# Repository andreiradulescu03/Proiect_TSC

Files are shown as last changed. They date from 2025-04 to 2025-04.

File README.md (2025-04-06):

# OpenBook – Proiect TSC 2025

Acest proiect reprezinta un prototip de eBook reader open-source, construit in jurul microcontrolerului ESP32-C6 si echipat cu afisaj E-Ink, baterie Li-Po, incarcare prin USB-C, slot microSD si senzori de mediu. Proiectul a inclus realizarea schemei electrice, a placii PCB, a modelului 3D complet si a fisierelor pentru fabricatie.

---

## Diagrama bloc

```mermaid
flowchart TB
  USB-C -->|5V| CHG["Battery Charger MCP73831"]
  CHG -->|Charging| BAT["LiPo Battery"]
  BAT --> LDO["3.3V LDO Regulator"]
  LDO -->|3.3V| ESP["ESP32-C6"]
  LDO -->|3.3V| EPD["E-Ink Display"]
  LDO -->|3.3V| SD["SD Card"]
  LDO -->|3.3V| BME["Sensor BME688"]
  LDO -->|3.3V| RTC["RTC DS3231"]
  LDO -->|3.3V| MAX["Battery Monitor MAX17048"]
  
  ESP -- SPI --> EPD
  ESP -- SPI --> SD
  ESP -- I2C --> BME
  ESP -- I2C --> RTC
  ESP -- I2C --> MAX
  ESP -- GPIO --> BTN["Buttons (3x)"]
```

---

## Functionalitate hardware

- **ESP32-C6** gestioneaza toate perifericele prin GPIO, SPI si I2C
- **Afisajul E-Ink** este controlat prin SPI si are semnale dedicate pentru RESET, DC si BUSY
- **Bateria Li-Po** este incarcata printr-un controler MCP73831 si monitorizata cu MAX17048
- **Senzorul BME688** masoara temperatura, umiditatea, presiunea si compusii volatili
- **Modulul RTC DS3231** mentine ora exacta si permite deep sleep eficient
- **Cardul microSD** este conectat la aceeasi magistrala SPI
- Toate componentele sunt montate pe layer-ul TOP si rutarea este realizata in 2 straturi

---

## Pinout ESP32-C6

| Componenta | Pin ESP32-C6 | Interfata |
|---|---|---|
| E-Ink BUSY | IO3 | GPIO |
| E-Ink DC | IO5 | GPIO |
| E-Ink RESET | IO23 | GPIO |
| E-Ink CS | IO10 | SPI |
| E-Ink MOSI | IO7 | SPI |
| E-Ink SCK | IO6 | SPI |
| SD Card CS | IO4 | SPI |
| SD Card MISO | IO2 | SPI |
| I2C SDA | IO18 | I2C |
| I2C SCL | IO19 | I2C |
| Butoane | GPIO10/11/12 | GPIO |

---

## Fisiere incluse

- `*.sch`, `*.brd` – schema electrica si design-ul PCB
- `Gerber/` – fisiere de productie
- `3D/` – modelul 3D al PCB-ului cu toate componentele atasate (baterie, ecran, carcasa)
- `BOM.csv` – lista de componente
- `README.md` – acest fisier

---

## Observatii

- Traseele de alimentare au latimea de 0.3mm, restul traseelor 0.15mm
- PCB-ul are grosimea de 1mm si contine planuri de masa pe ambele straturi
- Conectorii, ecranul si bateria au fost integrati in modelul 3D si testati pentru incadrare in carcasa
- Carcasa a fost importata si aliniata cu PCB-ul pentru randare
- Fisierele au fost verificate cu ERC si DRC

---

## Disclaimer subtil

Am invatat multe lucruri din acest proiect. Unele despre proiectare electronica. Majoritatea despre autocontrol.

---

# Bill of Materials
| Componenta | Link | Datasheet
| --- | --- |---|
|ESP32_WROVER_BME680_BME680|https://www.snapeda.com/parts/BME680/Bosch/view-part/?welcome=home|https://www.snapeda.com/parts/BME680/Bosch%20Sensortec/datasheet/|
|ESP32_WROVER_EAGLE-LTSPICE_CC0402|https://componentsearchengine.com/Datasheets/2/CC0402MRX5R5BB106.pdf|https://componentsearchengine.com/part-view/CC0402MRX5R5BB106/YAGEO|
|ESP32_WROVER_SPARKFUN-DISCRETESEMI_MOSFET_PCH-DMG2305UX-7|https://componentsearchengine.com/part-view/DMG2305UX-7/Diodes%20Incorporated|https://www.diodes.com//assets/Datasheets/DMG2305UX.pdf|
|ESP32C6_VARISTORCN1812|https://www.mouser.co.uk/ProductDetail/EPCOS-TDK/B72520T0350K062?qs=dEfas%2FXlABIszF52uu7vrg%3D%3D|https://www.tdk-electronics.tdk.com/inf/75/db/CTVS_14/Surge_protection_series.pdf|
|FH34SRJ-24S-0.5SH_99_|https://componentsearchengine.com/part-view/XC6220A331MR-G/Torex|https://product.torexsemi.com/system/files/series/xc6220.pdf|
|MAX17048G+T10|https://www.snapeda.com/parts/MAX17048G+T10/Analog+Devices/view-part/?ref=eda|https://www.snapeda.com/parts/MAX17048G+T10/Analog%20Devices/datasheet/|
|MBR0530|https://ro.mouser.com/ProductDetail/KYOCERA-AVX/SD0805S020S1R0?qs=jCA%252BPfw4LHbpkAoSnwrdjw%3D%3D|https://ro.mouser.com/datasheet/2/40/schottky-3165252.pdf|
|PGB1010603MR|https://www.snapeda.com/parts/PGB1010603MR/Littelfuse/view-part/?ref=eda|https://www.snapeda.com/parts/PGB1010603MR/Littelfuse%20Inc./datasheet/|
|RCL_CPOL-EUCT3528|https://ro.mouser.com/ProductDetail/Vishay-Sprague/TR3B106K025C1300?qs=jCGqFXxTmLdffnuDkXzk1g%3D%3D|https://www.vishay.com/docs/40080/tr3.pdf|
|SAMACSYS_PARTS_USB4110-GF-A|https://componentsearchengine.com/part-view/USB4110-GF-A/GCT%20(GLOBAL%20CONNECTOR%20TECHNOLOGY)|https://gct.co/files/drawings/usb4110.pdf|
|SI1308EDL-T1-GE3|https://componentsearchengine.com/part-view/SI1308EDL-T1-GE3/Vishay|https://componentsearchengine.com/Datasheets/1/SI1308EDL-T1-GE3.pdf|
|SJ|https://grabcad.com/library/solder-jumpers-1||
|USBLC6-2SC6Y|https://www.snapeda.com/parts/USBLC6-2SC6Y/STMicroelectronics/view-part/?ref=eda|https://www.snapeda.com/parts/USBLC6-2SC6Y/STMicroelectronics/datasheet/|
|W25Q512JVEIQ|https://www.snapeda.com/parts/W25Q512JVEIQ/Winbond+Electronics/view-part/?ref=eda|https://www.snapeda.com/parts/W25Q512JVEIQ/Winbond%20Electronics/datasheet/|
|XC6220A331MR-G|https://componentsearchengine.com/part-view/XC6220A331MR-G/Torex|https://product.torexsemi.com/system/files/series/xc6220.pdf|
| ESP32_WROVER_EAGLE-LTSPICE_RR0402  | https://www.snapeda.com/parts/RC0402FR-07226RL/Yageo/view-part/ |https://www.snapeda.com/parts/RC0402FR-07226RL/Yageo/datasheet/
| QWIIC_CONNECTORJS-1MM | https://www.snapeda.com/parts/PRT-14417/SparkFun/view-part/ |https://www.snapeda.com/parts/PRT-14417/SparkFun%20Electronics/datasheet/
|BUTTON_CUSYOMV1|https://industry.panasonic.com/global/en/downloads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|https://industry.panasonic.com/global/en/downloads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
|ESP32_WROVER_EAGLE-LTSPICE_CC0402|https://componentsearchengine.com/part-view/CC0402MRX5R5BB106/YAGEO|https://componentsearchengine.com/Datasheets/2/CC0402MRX5R5BB106.pdf
|CPH3225A|https://www.snapeda.com/parts/CPH3225A/Seiko+Instruments/view-part/?ref=eda|https://www.snapeda.com/parts/CPH3225A/Seiko%20Instruments/datasheet/|
|ADAFRUIT_LEDCHIP-LED0603|https://www.snapeda.com/parts/KP-1608SURCK/Kingbright/view-part/?ref=search&t=LED%200603|https://www.snapeda.com/parts/KP-1608SURCK/Kingbright/datasheet/
|112A-TAAR-R03_ATTEND|https://store.comet.bg/en/Catalogue/Product/43497/|https://store.comet.bg/en/Catalogue/Product/43497/|
|744043680IND_4828-WE-TPC_WRE|https://www.digikey.sg/en/models/1638515|https://www.we-online.com/components/products/datasheet/744043680.pdf
|BD5229G-TR|https://componentsearchengine.com/part-view/BD5229G-TR/ROHM%20Semiconductor|https://datasheet.datasheetarchive.com/originals/distributors/Datasheets_SAMA/f2b9741ef86007909f138d561a359946.pdf|
|CPH3225A|https://www.snapeda.com/parts/CPH3225A/Seiko+Instruments/view-part/?ref=eda|https://www.snapeda.com/parts/CPH3225A/Seiko%20Instruments/datasheet/|
|DS3231SN|https://www.snapeda.com/parts/DS3231SN%23/Analog+Devices/view-part/?ref=eda|https://www.snapeda.com/parts/DS3231SN%23/Analog%20Devices/datasheet/|
|ESP32-C6-WROOM-1-N8|https://www.snapeda.com/parts/ESP32-C6-WROOM-1-N8/Espressif+Systems/view-part/?ref=eda|https://www.snapeda.com/parts/ESP32-C6-WROOM-1-N8/Espressif%20Systems/datasheet/
|MCP73831|https://www.digikey.com/en/models/1874108|https://ww1.microchip.com/downloads/aemDocuments/documents/APID/ProductDocuments/DataSheets/MCP73831-Family-Data-Sheet-DS20001984H.pdf|

---

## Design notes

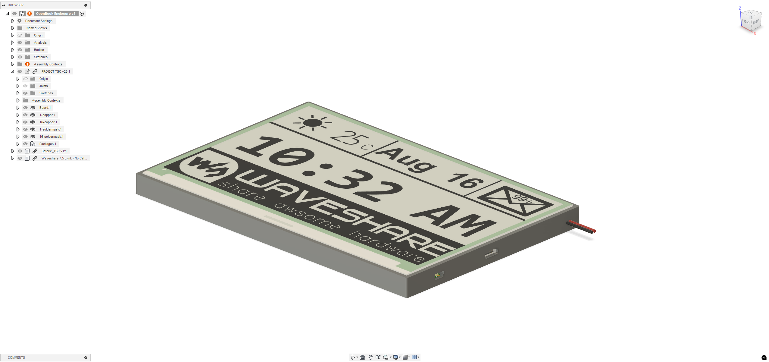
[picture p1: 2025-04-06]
Images/schema_pcb_3d_complet.png

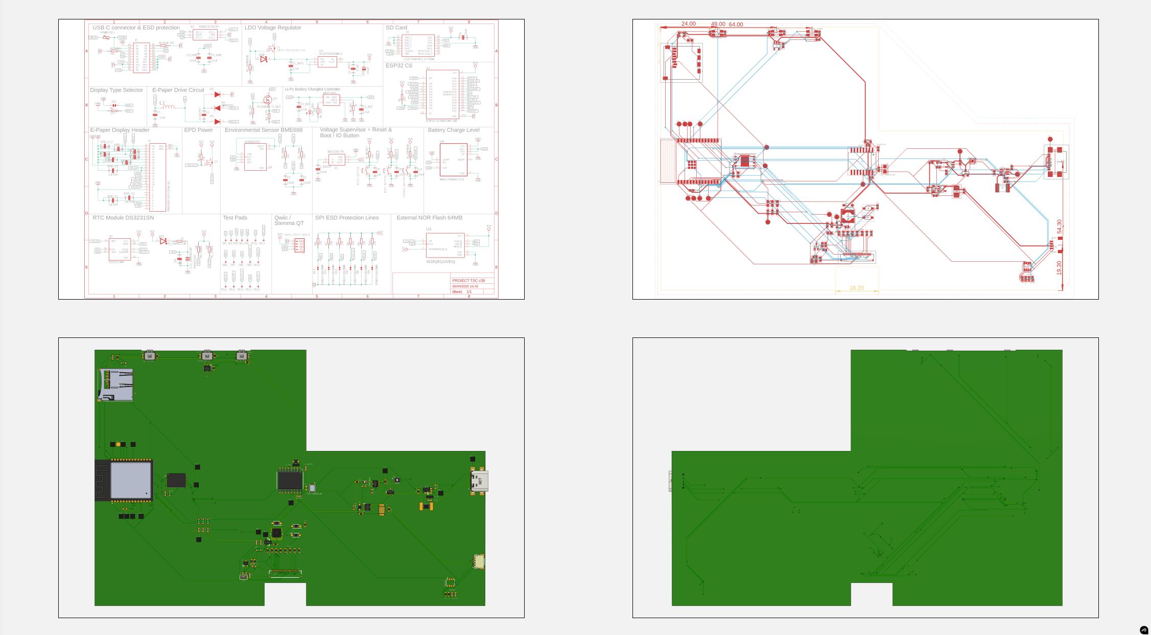
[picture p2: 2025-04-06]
Images/main.png

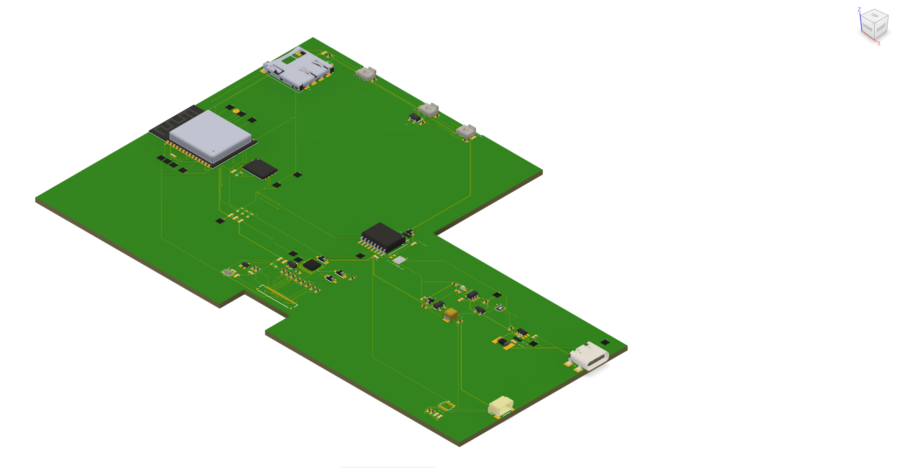
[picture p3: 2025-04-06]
Images/schema_pcb_3d_placa.png

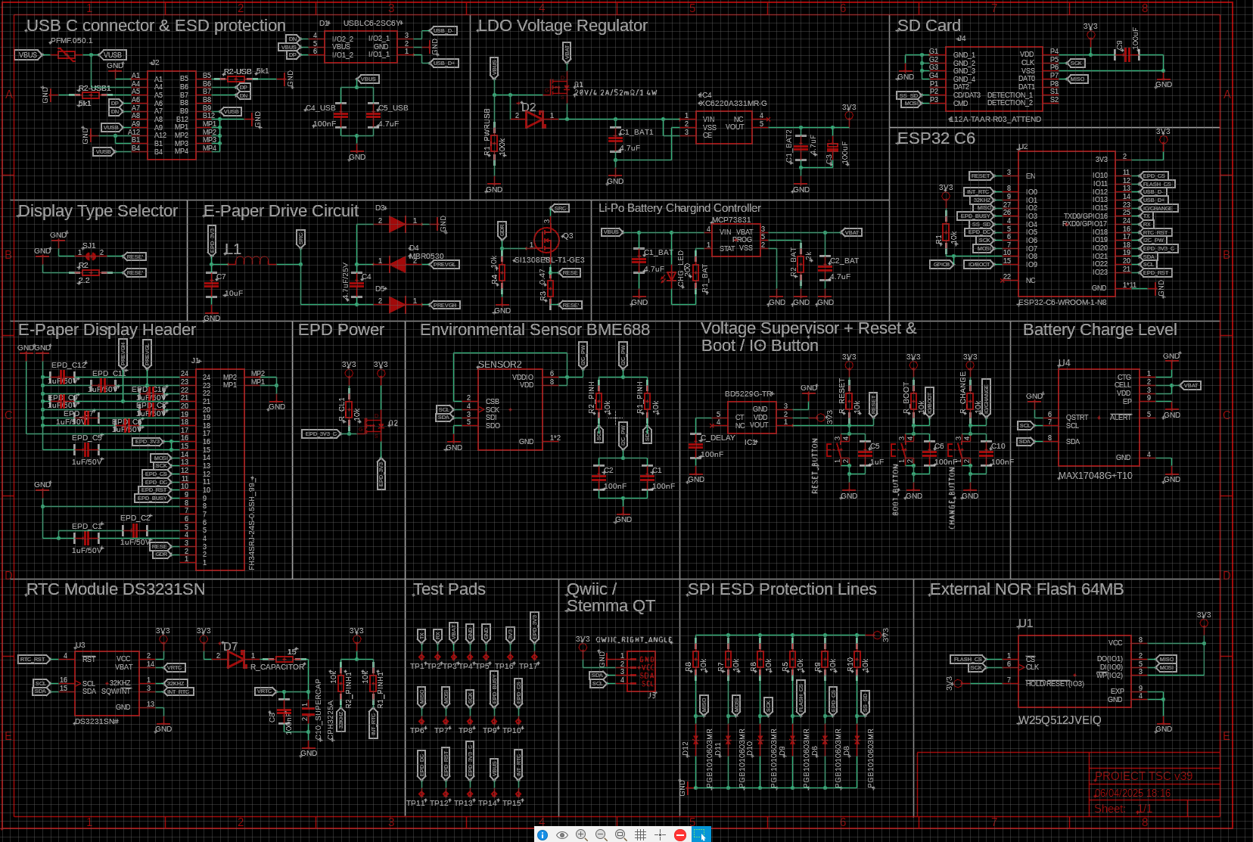
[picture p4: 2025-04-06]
Images/schema_electrica.png

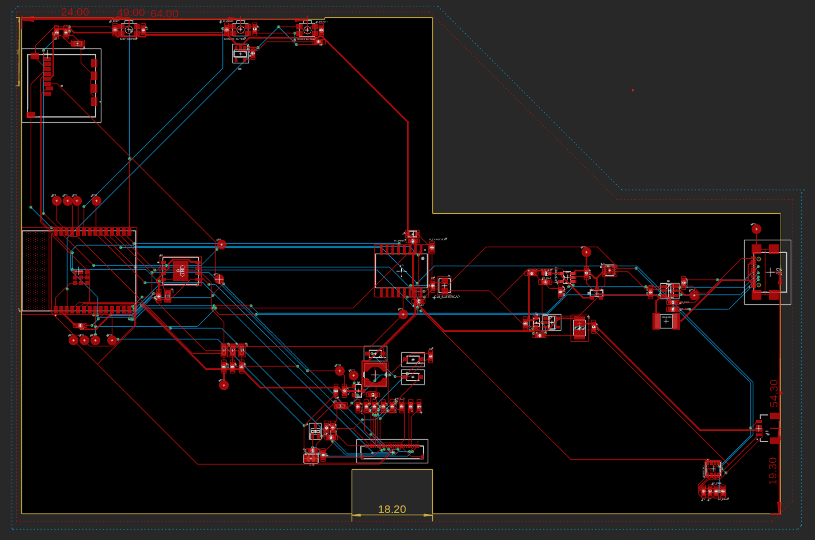
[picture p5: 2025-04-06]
Images/schema_pcb.png

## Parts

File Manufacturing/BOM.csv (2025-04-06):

Qty | Value | Device | Package | Parts | Description | ARROW_PART_NUMBER | ARROW_PRICE-STOCK | AVAILABILITY | CENTROID_NOT_SPECIFIED | CHECK_PRICES | COPYRIGHT | DATASHEET | DESCRIPTION | DIGIKEY_DESCRIPTION | DIGIKEY_PART_NUMBER | HEIGHT | LEAD_FREE | MANUFACTURER_NAME | MANUFACTURER_PART_NUMBER | MF | MFR_NAME | MOUSER_PART_NUMBER | MOUSER_PRICE-STOCK | MOUSER_TESTING_PART_NUMBER | MOUSER_TESTING_PRICE-STOCK | MP | MPN | PACKAGE | POPULARITY | PREFIX | PRICE | PROD_ID | PURCHASE-URL | ROHS | SNAPEDA_LINK | SPICEMODEL | SPICEPREFIX | TEMPERATURE_RANGE_HIGH | TEMPERATURE_RANGE_LOW | TP_SIGNAL_NAME | VALUE
1 |  | ADAFRUIT_LEDCHIP-LED0603 | ADAFRUIT_CHIP-LED0603 | CHG_LED | LED
1 |  | SJ | SJ | SJ1 | SMD solder JUMPER |  |  |  |  |  |  |  |  |  |  |  |  |  |  |  |  |  |  |  |  |  |  |  | 3
1 | 0.47 | ESP32_WROVER_EAGLE-LTSPICE_RR0402 | ESP32_WROVER_EAGLE-LTSPICE_R0402 | R3 | RESISTOR, European symbol |  |  |  |  |  |  |  |  |  |  |  |  |  |  |  |  |  |  |  |  |  |  |  |  |  |  |  |  |  |  | NONE | R
1 | 100k | ESP32_WROVER_EAGLE-LTSPICE_RR0402 | ESP32_WROVER_EAGLE-LTSPICE_R0402 | R1_PWRUSB | RESISTOR, European symbol |  |  |  |  |  |  |  |  |  |  |  |  |  |  |  |  |  |  |  |  |  |  |  |  |  |  |  |  |  |  | NONE | R
7 | 100nF | EAGLE-LTSPICE_CC0402 | EAGLE-LTSPICE_C0402 | C1, C2, C4_USB, C6, C8, C10, C_DELAY | CAPACITOR, European symbol |  |  |  |  |  |  |  |  |  |  |  |  |  |  |  |  |  |  |  |  |  |  |  |  |  |  |  |  |  |  | NONE | C
1 | 100uF | EAGLE-LTSPICE_CC0402 | EAGLE-LTSPICE_C0402 | C9 | CAPACITOR, European symbol |  |  |  |  |  |  |  |  |  |  |  |  |  |  |  |  |  |  |  |  |  |  |  |  |  |  |  |  |  |  | NONE | C
1 | 100uF | RCL_CPOL-EUCT3528 | RCL_CT3528 | C3 | POLARIZED CAPACITOR, European symbol |  |  |  |  |  |  |  |  |  |  |  |  |  |  |  |  |  |  |  |  |  |  |  | 0 |  |  |  |  |  |  |  | C
16 | 10k | ESP32_WROVER_EAGLE-LTSPICE_RR0402 | ESP32_WROVER_EAGLE-LTSPICE_R0402 | R1, R1_PINH, R1_PINH1, R2_PINH, R2_PINH1, R4, R5, R6, R7, R8, R9, R10, R_BOOT, R_CHANGE, R_CL1, R_RESET | RESISTOR, European symbol |  |  |  |  |  |  |  |  |  |  |  |  |  |  |  |  |  |  |  |  |  |  |  |  |  |  |  |  |  |  | NONE | R
1 | 10uF | EAGLE-LTSPICE_CC0402 | EAGLE-LTSPICE_C0402 | C7 | CAPACITOR, European symbol |  |  |  |  |  |  |  |  |  |  |  |  |  |  |  |  |  |  |  |  |  |  |  |  |  |  |  |  |  |  | NONE | C
1 | 112A-TAAR-R03_ATTEND | 112A-TAAR-R03_ATTEND | 112ATAARR03ATTEND | J4 | Micro SD Card Socket, Push-Push Type, Top Mount, SMT, H=1.83mm, 10u |  |  |  |  |  |  |  | Micro SD Card Socket | Push-Push Type | Top Mount | SMT | H=1.83mm | 10u |  |  | 1.9mm |  | ATTEND | 112A-TAAR-R03 ATTEND
1 | 15 | ESP32_WROVER_EAGLE-LTSPICE_RR0402 | ESP32_WROVER_EAGLE-LTSPICE_R0402 | R_CAPACITOR | RESISTOR, European symbol |  |  |  |  |  |  |  |  |  |  |  |  |  |  |  |  |  |  |  |  |  |  |  |  |  |  |  |  |  |  | NONE | R
1 | 1uF | EAGLE-LTSPICE_CC0402 | EAGLE-LTSPICE_C0402 | C5 | CAPACITOR, European symbol |  |  |  |  |  |  |  |  |  |  |  |  |  |  |  |  |  |  |  |  |  |  |  |  |  |  |  |  |  |  | NONE | C
10 | 1uF/50V | EAGLE-LTSPICE_CC0402 | EAGLE-LTSPICE_C0402 | EPD_C1, EPD_C2, EPD_C5, EPD_C6, EPD_C7, EPD_C8, EPD_C9, EPD_C10, EPD_C11, EPD_C12 | CAPACITOR, European symbol |  |  |  |  |  |  |  |  |  |  |  |  |  |  |  |  |  |  |  |  |  |  |  |  |  |  |  |  |  |  | NONE | C
1 | 2.2 | ESP32_WROVER_EAGLE-LTSPICE_RR0402 | ESP32_WROVER_EAGLE-LTSPICE_R0402 | R2 | RESISTOR, European symbol |  |  |  |  |  |  |  |  |  |  |  |  |  |  |  |  |  |  |  |  |  |  |  |  |  |  |  |  |  |  | NONE | R
1 | 200 | ESP32_WROVER_EAGLE-LTSPICE_RR0402 | ESP32_WROVER_EAGLE-LTSPICE_R0402 | R1_BAT | RESISTOR, European symbol |  |  |  |  |  |  |  |  |  |  |  |  |  |  |  |  |  |  |  |  |  |  |  |  |  |  |  |  |  |  | NONE | R
2 | 20V/4.2A/52mO/1.4W | ESP32_WROVER_SPARKFUN-DISCRETESEMI_MOSFET_PCH-DMG2305UX-7 | ESP32_WROVER_SPARKFUN-DISCRETESEMI_SOT23-3 | Q1, Q2 | P-channel MOSFETs |  |  |  |  |  |  |  |  |  |  |  |  |  |  |  |  |  |  |  |  |  |  |  |  |  |  | TRAN-14388 |  |  |  |  |  |  |  |  | 20V/4.2A/52mO/1.4W
1 | 2k | ESP32_WROVER_EAGLE-LTSPICE_RR0402 | ESP32_WROVER_EAGLE-LTSPICE_R0402 | R2_BAT | RESISTOR, European symbol |  |  |  |  |  |  |  |  |  |  |  |  |  |  |  |  |  |  |  |  |  |  |  |  |  |  |  |  |  |  | NONE | R
5 | 4.7uF | EAGLE-LTSPICE_CC0402 | EAGLE-LTSPICE_C0402 | C1_BAT, C1_BAT1, C1_BAT2, C2_BAT, C5_USB | CAPACITOR, European symbol |  |  |  |  |  |  |  |  |  |  |  |  |  |  |  |  |  |  |  |  |  |  |  |  |  |  |  |  |  |  | NONE | C
1 | 4.7uF/25V | EAGLE-LTSPICE_CC0402 | EAGLE-LTSPICE_C0402 | C4 | CAPACITOR, European symbol |  |  |  |  |  |  |  |  |  |  |  |  |  |  |  |  |  |  |  |  |  |  |  |  |  |  |  |  |  |  | NONE | C
2 | 5k1 | ESP32_WROVER_EAGLE-LTSPICE_RR0402 | ESP32_WROVER_EAGLE-LTSPICE_R0402 | R2-USB, R2-USB1 | RESISTOR, European symbol |  |  |  |  |  |  |  |  |  |  |  |  |  |  |  |  |  |  |  |  |  |  |  |  |  |  |  |  |  |  | NONE | R
1 | 68uH | 744043680IND_4828-WE-TPC_WRE | IND_4828-WE-TPC_WRE | L1 |  |  |  |  |  |  | Copyright (C) 2024 Ultra Librarian. All rights reserved. |  |  |  |  |  |  |  | 744043680 |  | Wurth Electronics
1 | BD5229G-TR | BD5229G-TR | SOT95P280X125-5N | IC1 | Voltage Detector with Adjustable Delay Time: CMOS processes are utilized to develop high precision, low current consumption CMOS reset ICs that allow arbitrary setting of the delay time. The extensive lineup includes both Nch Open Drain and CMOS output types in a wide range of detection voltages (from 2.3V to 6.0V, in 0.1V steps), enabling selection of the ideal solution based on customer requirements. In addition, the entire series is of course both lead-free and RoHS-compliant. |  |  |  |  |  |  |  | Voltage Detector with Adjustable Delay Time: CMOS processes are utilized to develop high precision | low current consumption CMOS reset ICs that allow arbitrary setting of the delay time. The extensive lineup includes both Nch Open Drain and CMOS output types in a wide range of detection voltages (from 2.3V to 6.0V | in 0.1V steps) | enabling selection of the ideal solution based on customer requirements. In addition | the entire series is of course both lead-free and RoHS-compliant. |  |  | 1.25mm |  | ROHM Semiconductor | BD5229G-TR |  |  | 755-BD5229G-TR | https://www.mouser.co.uk/ProductDetail/ROHM-Semiconductor/BD5229G-TR?qs=4kLU8WoGk0vvnhrrYwdszw%3D%3D
3 | BUTTON_CUSYOMV1 | BUTTON_CUSYOMV1 | MYBUTTON | BOOT_BUTTON, CHANGE_BUTTON, RESET_BUTTON
1 | CPH3225A | CPH3225A | CAPCP3225X100N | C10_SUPERCAP | Cap 0.011F 3.3V 1210 Flat Check availability |  |  | Not in stock |  | https://www.snapeda.com/parts/CPH3225A/Seiko+Instruments/view-part/?ref=eda |  |  | 11 mF (EDLC) Supercapacitor 3.3 V 1210 (3225 Metric) - - |  |  |  |  |  |  | Seiko Instruments |  |  |  |  |  | CPH3225A |  | 1210 Seiko |  |  | None |  | https://www.snapeda.com/api/url_track_click_mouser/?unipart_id=562593&manufacturer=Seiko Instruments&part_name=CPH3225A&search_term=None |  | https://www.snapeda.com/parts/CPH3225A/Seiko+Instruments/view-part/?ref=snap
1 | DS3231SN# | DS3231SN# | SOIC127P1032X265-16N | U3 | Real Time Clock Serial 16-Pin SOIC W T/R Check availability |  |  | In Stock |  | https://www.snapeda.com/parts/DS3231SN%23/Analog+Devices/view-part/?ref=eda |  |  | Extremely Accurate I²C-Integrated RTC/TCXO/Crystal |  |  |  |  |  |  | Analog Devices |  |  |  |  |  | DS3231SN# |  | SOIC-16 Maxim |  |  | None |  | https://www.snapeda.com/api/url_track_click_mouser/?unipart_id=99048&manufacturer=Analog Devices&part_name=DS3231SN#&search_term=None |  | https://www.snapeda.com/parts/DS3231SN%23/Analog+Devices/view-part/?ref=snap
1 | ESP32-C6-WROOM-1-N8 | ESP32-C6-WROOM-1-N8 | XCVR_ESP32-C6-WROOM-1-N8 | U2 | Check availability |  |  | In Stock |  | https://www.snapeda.com/parts/ESP32-C6-WROOM-1-N8/Espressif+Systems/view-part/?ref=eda |  |  | Multiprotocol Modules ESP32-C6 module | Wi-Fi 6 in 2.4 GHz band | Bluetooth 5 | Zigbee 3.0 and Thread. ESP34-WROOM Compatible - ENGINEERING SAMPLE |  |  |  |  |  |  | Espressif Systems |  |  |  |  |  | ESP32-C6-WROOM-1-N8 |  | None |  |  | None |  |  |  | https://www.snapeda.com/parts/ESP32-C6-WROOM-1-N8/Espressif+Systems/view-part/?ref=snap
1 | ESP32C6_VARISTORCN1812 | ESP32C6_VARISTORCN1812 | ESP32C6_VARISTOR_CT/CN1812 | PFMF.050.1 | VARISTOR |  |  |  |  |  |  |  |  |  |  |  |  |  |  |  |  |  |  |  |  |  |  |  | 0
2 | ESP32_WROVER_AVX---SD0805S020S1R0_AVX_SD0805S020S1R0_0_0AVX_SD0805S020S1R0_0_0 | ESP32_WROVER_AVX---SD0805S020S1R0_AVX_SD0805S020S1R0_0_0AVX_SD0805S020S1R0_0_0 | ESP32_WROVER_AVX---SD0805S020S1R0_AVX_SD0805S020S1R0_0 | D2, D7 | Schottky Barrier Rectifier Diode |  |  |  | No |  |  | http://datasheets.avx.com/schottky.pdf |  | DIODE SCHOTTKY 20V 1A 0805 | 478-7800-1-ND |  | yes |  |  | AVX |  | 581-SD0805S020S1R0 |  |  |  |  |  | 0805 (2012 metric) |  | D |  |  |  | yes |  |  |  | +125°C | -55°C
1 | ESP32_WROVER_BME680_BME680 | ESP32_WROVER_BME680_BME680 | ESP32_WROVER_BME680_PSON80P300X300X100-8N | SENSOR2 | Integrated Environmental Unit |  |  | Unavailable |  |  |  |  | Integrated Environmental Unit |  |  |  |  |  |  | Bosch Sensortec |  |  |  |  |  | BME680 |  | LGA-8 Bosch Tools |  |  | None
1 | ESP32_WROVER_SPARKFUN-IC-POWER_MCP73831 | ESP32_WROVER_SPARKFUN-IC-POWER_MCP73831 | ESP32_WROVER_SPARKFUN-IC-POWER_SOT23-5 | MCP73831 | MCP73831T Li-Ion, Li-Pol Controller |  |  |  |  |  |  |  |  |  |  |  |  |  |  |  |  |  |  |  |  |  |  |  |  |  |  | IC-09995
1 | FH34SRJ-24S-0.5SH_99_ | FH34SRJ-24S-0.5SH_99_ | FH34SRJ24S05SH99 | J1 | (0.50mm) Surface Mount, Right Angle |  |  |  |  |  |  |  | 24 Position FFC | FPC Connector Contacts | (0.50mm) Surface Mount | Right Angle |  |  | 1.1mm |  | Hirose | FH34SRJ-24S-0.5SH(99) |  |  | 798-FH34SRJ24S05SH99 | https://www.mouser.co.uk/ProductDetail/Hirose-Connector/FH34SRJ-24S-0.5SH99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
1 | MAX17048G+T10 | MAX17048G+T10 | SON50P200X200X80-9N | U4 | Check availability |  |  | In Stock |  | https://www.snapeda.com/parts/MAX17048G+T10/Analog+Devices/view-part/?ref=eda |  |  | 3µA 1-Cell/2-Cell Fuel Gauge with ModelGauge |  |  |  |  |  |  | Analog Devices |  |  |  |  |  | MAX17048G+T10 |  | TDFN-8 Maxim |  |  | None |  | https://www.snapeda.com/api/url_track_click_mouser/?unipart_id=329239&manufacturer=Analog Devices&part_name=MAX17048G+T10&search_term=None |  | https://www.snapeda.com/parts/MAX17048G+T10/Analog+Devices/view-part/?ref=snap
3 | MBR0530 | MBR0530 | SOD3716X135N | D3, D4, D5 | ON SEMICONDUCTOR - MBR0530 - DIODE, SCHOTTKY, 0.5A, 30V, SOD-123 |  |  | In Stock |  | https://www.snapeda.com/parts/MBR0530/Onsemi/view-part/?ref=eda |  |  | Diode Schottky 30 V 500mA Surface Mount SOD-123 |  |  |  |  |  |  | ON Semiconductor |  |  |  |  |  | MBR0530 |  | SOD-123-2 ON Semiconductor |  |  | None |  | https://www.snapeda.com/api/url_track_click_mouser/?unipart_id=179458&manufacturer=ON Semiconductor&part_name=MBR0530&search_term=None |  | https://www.snapeda.com/parts/MBR0530/Onsemi/view-part/?ref=snap
6 | PGB1010603MR | PGB1010603MR | DIOC1608X36N | D6, D8, D9, D10, D11, D12 | Check availability |  |  | In Stock |  | https://www.snapeda.com/parts/PGB1010603MR/Littelfuse/view-part/?ref=eda |  |  | 150V (Typ) Clamp - Ipp Tvs Diode Surface Mount 0603 (1608 Metric) |  |  |  |  |  |  | Littelfuse Inc. |  |  |  |  |  | PGB1010603MR |  | 0603 Littelfuse Inc. |  |  | None |  | https://www.snapeda.com/api/url_track_click_mouser/?unipart_id=5659453&manufacturer=Littelfuse Inc.&part_name=PGB1010603MR&search_term=None |  | https://www.snapeda.com/parts/PGB1010603MR/Littelfuse/view-part/?ref=snap
1 | QWIIC_RIGHT_ANGLE | QWIIC_CONNECTORJS-1MM | JST04_1MM_RA | J3 | SparkFun I2C Standard Qwiic Connector |  |  |  |  |  |  |  |  |  |  |  |  |  |  |  |  |  |  |  |  |  |  |  |  |  |  | CONN-13694 |  |  |  |  |  |  |  |  | QWIIC_RIGHT_ANGLE
1 | SAMACSYS_PARTS_USB4110-GF-A | SAMACSYS_PARTS_USB4110-GF-A | SAMACSYS_PARTS_USB4110GFA | J2 | CONN USB 2.0 TYPE-C R/A SMT |  |  |  |  |  |  |  | CONN USB 2.0 TYPE-C R/A SMT |  |  | 3.26mm |  | GCT (GLOBAL CONNECTOR TECHNOLOGY) | USB4110-GF-A |  |  | 640-USB4110-GF-A | https://www.mouser.co.uk/ProductDetail/GCT/USB4110-GF-A?qs=KUoIvG%2F9IlYiZvIXQjyJeA%3D%3D
1 | SI1308EDL-T1-GE3 | SI1308EDL-T1-GE3 | SOT65P210X110-3N | Q3 | MOSFET N-Ch 30V 1.5A TrenchFET SC70 Vishay Si1308EDL-T1-GE3 N-channel MOSFET Transistor, 1.5 A, 30 V, 3-Pin SC-70 |  |  | In Stock |  | https://www.snapeda.com/parts/SI1308EDL-T1-GE3/Vishay+Siliconix/view-part/?ref=eda |  |  | Si1308EDL-T1-GE3 N-channel MOSFET Transistor | 1.5 A | 30 V | 3-Pin SC-70 | Siliconix / Vishay SI1308EDL-T1-GE3 |  |  |  |  |  |  | Vishay Siliconix |  |  |  |  |  | SI1308EDL-T1-GE3 |  | SOT-323 Vishay Semiconductor |  |  | None |  | https://www.snapeda.com/api/url_track_click_mouser/?unipart_id=274603&manufacturer=Vishay Siliconix&part_name=SI1308EDL-T1-GE3&search_term=None |  | https://www.snapeda.com/parts/SI1308EDL-T1-GE3/Vishay+Siliconix/view-part/?ref=snap
17 | TPTP20R | TPTP20R | TP20R | TP1, TP2, TP3, TP4, TP5, TP6, TP7, TP8, TP9, TP10, TP11, TP12, TP13, TP14, TP15, TP16, TP17 | Test pad |  |  |  |  |  |  |  |  |  |  |  |  |  |  |  |  |  |  |  |  |  |  |  | 2
1 | USBLC6-2SC6Y | USBLC6-2SC6Y | SOT95P280X145-6N | D1 | Low Cap. ESD Protection Auto SOT-23-6 STMicroelectronics USBLC6-2SC6Y, Dual Uni-Directional TVS Diode Array, 6-Pin SOT-23 |  |  | In Stock |  | https://www.snapeda.com/parts/USBLC6-2SC6Y/STMicroelectronics/view-part/?ref=eda |  |  | 17V Clamp 5A (8/20µs) Ipp Tvs Diode Surface Mount SOT-23-6 |  |  |  |  |  |  | STMicroelectronics |  |  |  |  |  | USBLC6-2SC6Y |  | SOT-23-6 STMicroelectronics |  |  | None |  |  |  | https://www.snapeda.com/parts/USBLC6-2SC6Y/STMicroelectronics/view-part/?ref=snap
1 | W25Q512JVEIQ | W25Q512JVEIQ | SON127P600X800X80-9N | U1 | Check availability |  |  | In Stock |  | https://www.snapeda.com/parts/W25Q512JVEIQ/Winbond+Electronics/view-part/?ref=eda |  |  | FLASH - NOR Memory IC 512Mb (64M x 8) SPI - Quad I/O 133 MHz 8-WSON (8x6) |  |  |  |  |  |  | Winbond Electronics |  |  |  |  |  | W25Q512JVEIQ |  | Package |  |  | None |  |  |  | https://www.snapeda.com/parts/W25Q512JVEIQ/Winbond+Electronics/view-part/?ref=snap
1 | XC6220A331MR-G | XC6220A331MR-G | SOT95P280X120-5N | IC4 | LDO Voltage Regulators |  |  |  |  |  |  |  | LDO Voltage Regulators |  |  | 1.2mm |  | Torex | XC6220A331MR-G |  |  | 865-XC6220A331MR-G | https://www.mouser.co.uk/ProductDetail/Torex-Semiconductor/XC6220A331MR-G?qs=AsjdqWjXhJ8ZSWznL1J0gg%3D%3D

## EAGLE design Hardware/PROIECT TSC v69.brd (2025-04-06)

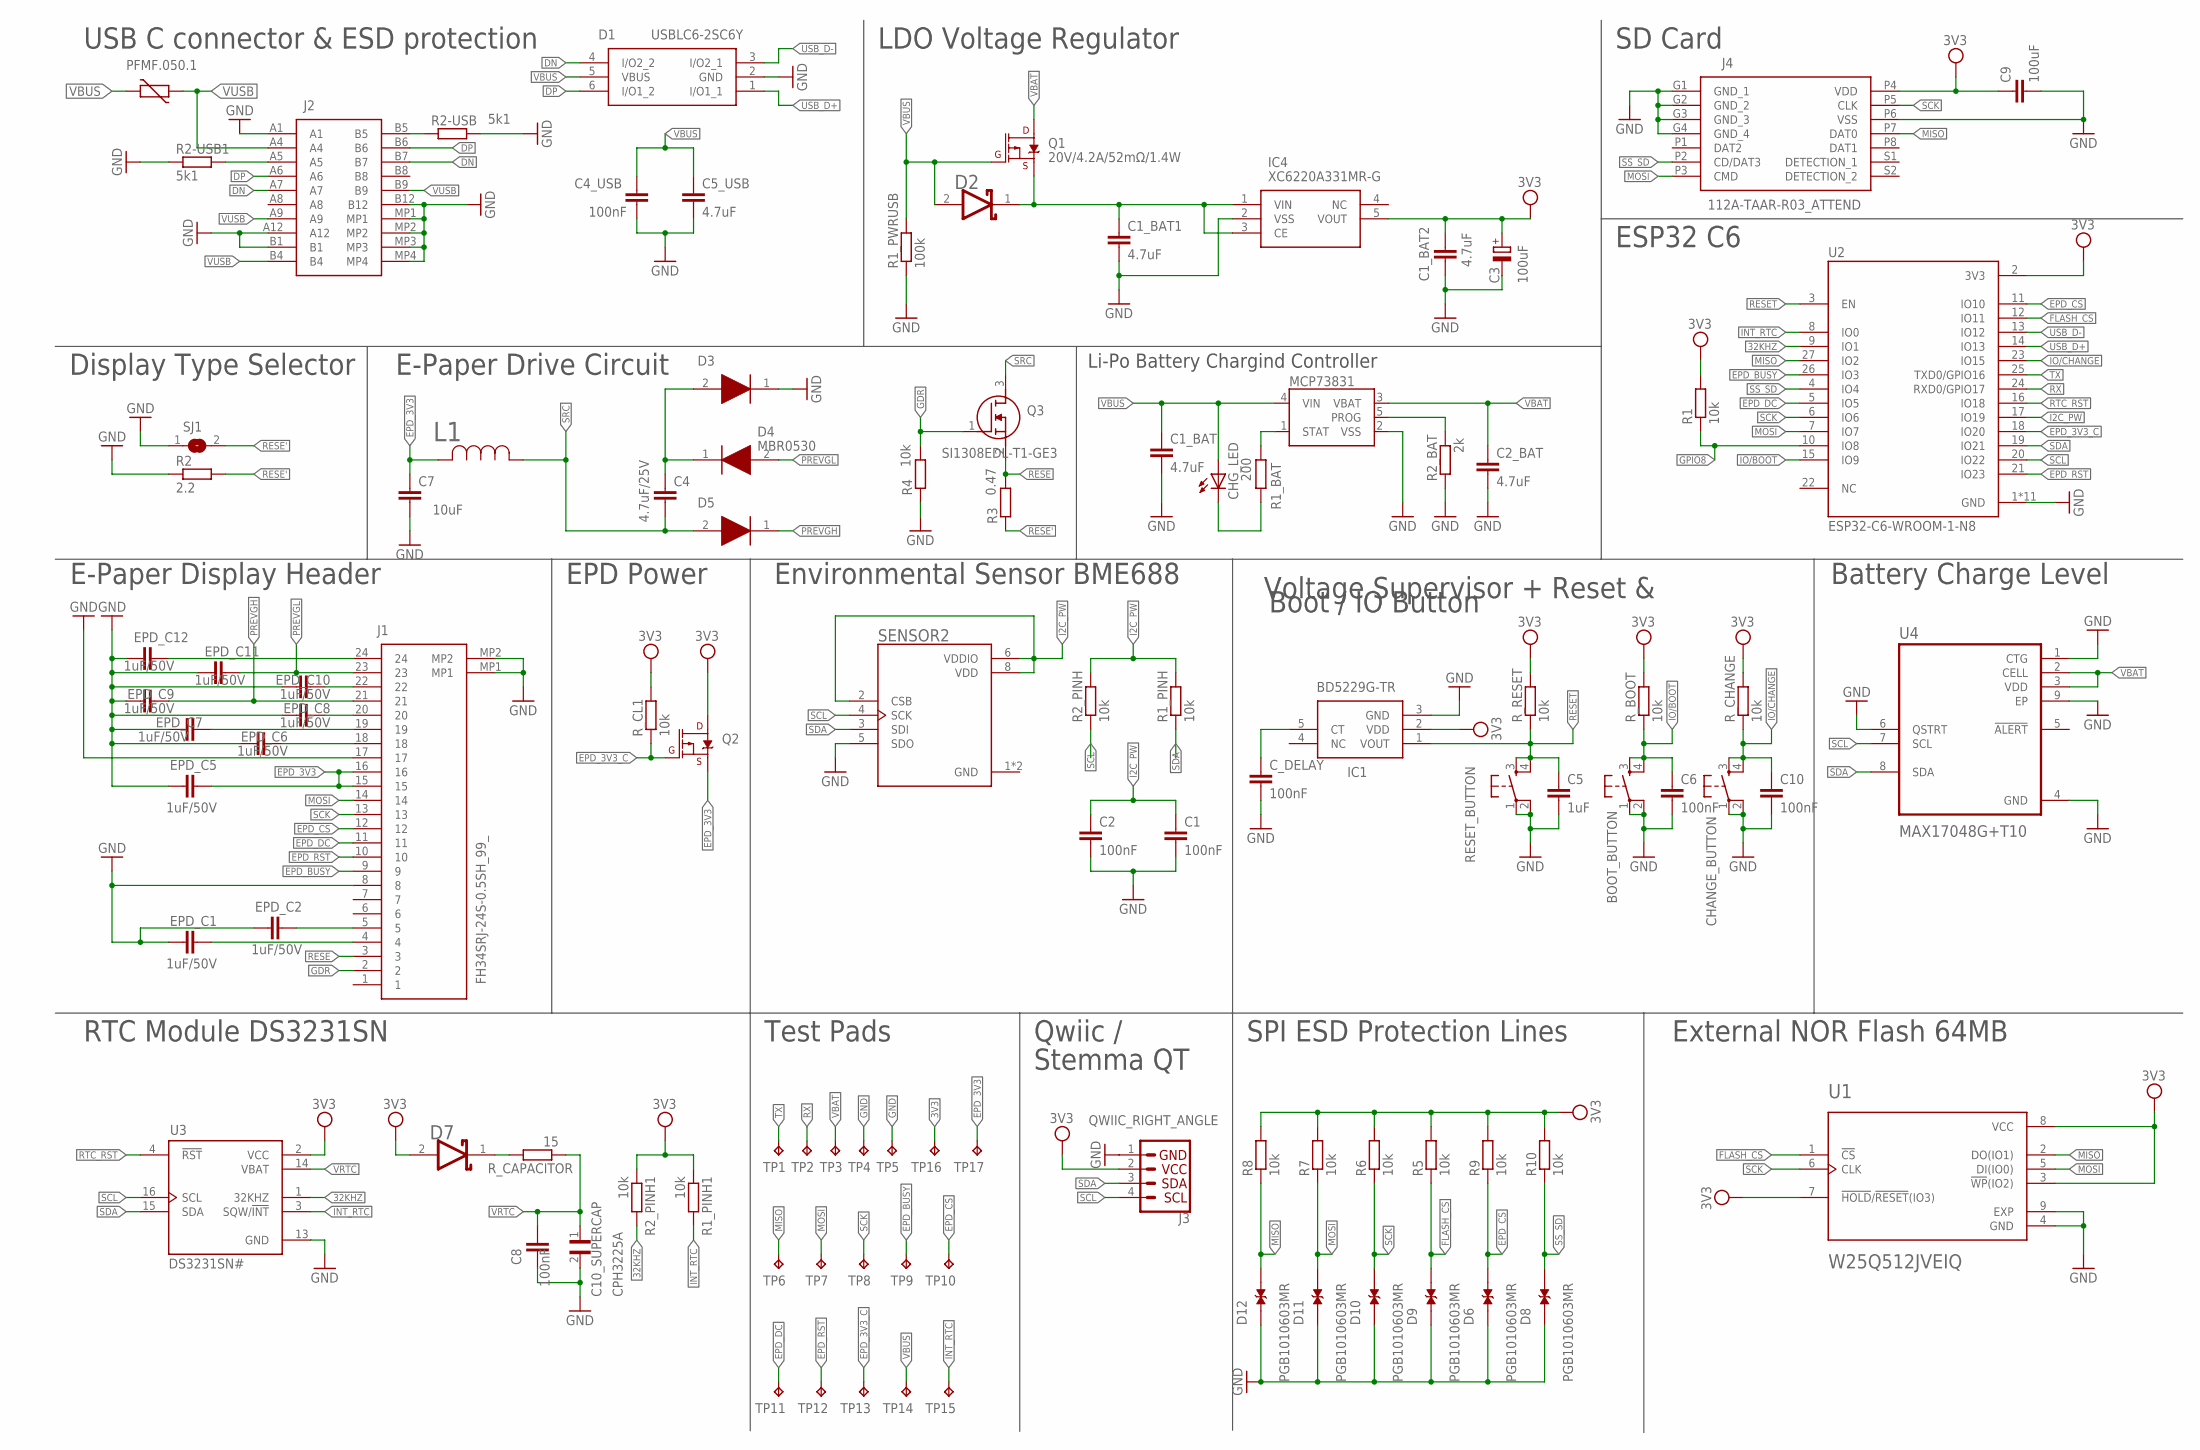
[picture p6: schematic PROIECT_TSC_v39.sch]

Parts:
BOOT_BUTTON: BUTTON_CUSYOMV1; MYBUTTON
C1, C2, C4_USB, C6, C8, C10: 100nF; EAGLE-LTSPICE_C0402
C1_BAT, C1_BAT1, C1_BAT2, C2_BAT, C5_USB: 4.7uF; EAGLE-LTSPICE_C0402
C3: 100uF; RCL_CT3528
C4: 4.7uF/25V; EAGLE-LTSPICE_C0402
C5: 1uF; EAGLE-LTSPICE_C0402
C7: 10uF; EAGLE-LTSPICE_C0402
C9: 100uF; EAGLE-LTSPICE_C0402
C10_SUPERCAP: CPH3225A; CAPCP3225X100N
CHANGE_BUTTON: BUTTON_CUSYOMV1; MYBUTTON
CHG_LED: ADAFRUIT_LEDCHIP-LED0603; ADAFRUIT_CHIP-LED0603
C_DELAY: 100nF; EAGLE-LTSPICE_C0402
D1: USBLC6-2SC6Y; SOT95P280X145-6N
D2, D7: ESP32_WROVER_AVX---SD0805S020S1R0_AVX_SD0805S020S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; ESP32_WROVER_AVX---SD0805S020S1R0_AVX_SD0805S020S1R0_0
D3, D4, D5: MBR0530; SOD3716X135N
D6, D8, D9, D10, D11, D12: PGB1010603MR; DIOC1608X36N
EPD_C1, EPD_C2, EPD_C5, EPD_C6, EPD_C7, EPD_C8, EPD_C9, EPD_C10, EPD_C11, EPD_C12: 1uF/50V; EAGLE-LTSPICE_C0402
IC1: BD5229G-TR; SOT95P280X125-5N
IC4: XC6220A331MR-G; SOT95P280X120-5N
J1: FH34SRJ-24S-0.5SH_99_; FH34SRJ24S05SH99
J2: SAMACSYS_PARTS_USB4110-GF-A; SAMACSYS_PARTS_USB4110GFA
J3: QWIIC_RIGHT_ANGLE; JST04_1MM_RA
J4: 112A-TAAR-R03_ATTEND; 112ATAARR03ATTEND
L1: 68uH; IND_4828-WE-TPC_WRE
MCP73831: ESP32_WROVER_SPARKFUN-IC-POWER_MCP73831; ESP32_WROVER_SPARKFUN-IC-POWER_SOT23-5
PFMF.050.1: ESP32C6_VARISTORCN1812; ESP32C6_VARISTOR_CT/CN1812
Q1, Q2: 20V/4.2A/52mΩ/1.4W; ESP32_WROVER_SPARKFUN-DISCRETESEMI_SOT23-3
Q3: SI1308EDL-T1-GE3; SOT65P210X110-3N
R1, R1_PINH, R1_PINH1, R2_PINH, R2_PINH1, R4, R5, R6, R7, R8, R9, R10: 10k; ESP32_WROVER_EAGLE-LTSPICE_R0402
R1_BAT: 200; ESP32_WROVER_EAGLE-LTSPICE_R0402
R1_PWRUSB: 100k; ESP32_WROVER_EAGLE-LTSPICE_R0402
R2: 2.2; ESP32_WROVER_EAGLE-LTSPICE_R0402
R2-USB, R2-USB1: 5k1; ESP32_WROVER_EAGLE-LTSPICE_R0402
R2_BAT: 2k; ESP32_WROVER_EAGLE-LTSPICE_R0402
R3: 0.47; ESP32_WROVER_EAGLE-LTSPICE_R0402
RESET_BUTTON: BUTTON_CUSYOMV1; MYBUTTON
R_BOOT: 10k; ESP32_WROVER_EAGLE-LTSPICE_R0402
R_CAPACITOR: 15; ESP32_WROVER_EAGLE-LTSPICE_R0402
R_CHANGE: 10k; ESP32_WROVER_EAGLE-LTSPICE_R0402
R_CL1: 10k; ESP32_WROVER_EAGLE-LTSPICE_R0402
R_RESET: 10k; ESP32_WROVER_EAGLE-LTSPICE_R0402
SENSOR2: ESP32_WROVER_BME680_BME680; ESP32_WROVER_BME680_PSON80P300X300X100-8N
SJ1: SJ
TP1, TP2, TP3, TP4, TP5, TP6, TP7, TP8, TP9, TP10, TP11, TP12, TP13, TP14, TP15, TP16, TP17: TPTP20R; TP20R
U1: W25Q512JVEIQ; SON127P600X800X80-9N
U2: ESP32-C6-WROOM-1-N8; XCVR_ESP32-C6-WROOM-1-N8
U3: DS3231SN#; SOIC127P1032X265-16N
U4: MAX17048G+T10; SON50P200X200X80-9N

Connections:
3V3: C1_BAT2.1, C3.+, C9.1, D7.2 (ANODE), IC1.2 (VDD), IC4.5 (VOUT), J3.2, J4.P4 (VDD), Q2.3 (D), R1.2, R1_PINH1.1, R2_PINH1.1, R5.2, R6.2, R7.2, R8.2, R9.2, R10.2, R_BOOT.2, R_CHANGE.2, R_CL1.2, R_RESET.2, TP16.TP, U1.3 (!WP!(IO2)), U1.7 (!HOLD!/!RESET!(IO3)), U1.8 (VCC), U2.2 (3V3), U3.2 (VCC)
32KHZ: R2_PINH1.2, U2.9 (IO1), U3.1 (32KHZ)
DN: D1.4 (I/O2_2), J2.A7, J2.B7
DP: D1.6 (I/O1_2), J2.A6, J2.B6
EPD_3V3: C7.1, EPD_C5.2, J1.15, J1.16, L1.2, Q2.2 (S), TP17.TP
EPD_3V3_C: Q2.1 (G), R_CL1.1, TP13.TP, U2.18 (IO20)
EPD_BUSY: J1.9, TP9.TP, U2.26 (IO3)
EPD_CS: D6.2, J1.12, R9.1, TP10.TP, U2.11 (IO10)
EPD_DC: J1.11, TP11.TP, U2.5 (IO5)
EPD_RST: J1.10, TP12.TP, U2.21 (IO23)
FLASH_CS: D9.2, R5.1, U1.1 (!CS), U2.12 (IO11)
GDR: J1.2, Q3.1 (G), R4.2
GND: BOOT_BUTTON.1, BOOT_BUTTON.2, C1.2, C1_BAT.2, C1_BAT1.2, C1_BAT2.2, C2.2, C2_BAT.2, C3.-, C4_USB.2, C5.2, C5_USB.2, C6.2, C7.2, C8.1, C9.2, C10.2, C10_SUPERCAP.2, CHANGE_BUTTON.1, CHANGE_BUTTON.2, C_DELAY.2, D1.2 (GND), D3.1 (K), D6.1, D8.1, D9.1, D10.1, D11.1, D12.1, EPD_C1.1, EPD_C2.1, EPD_C5.1, EPD_C6.1, EPD_C7.1, EPD_C8.1, EPD_C9.1, EPD_C10.1, EPD_C11.1, EPD_C12.1, IC1.3 (GND), IC4.2 (VSS), J1.8, J1.17, J1.MP1, J1.MP2, J2.A1, J2.A12, J2.B1, J2.B12, J2.MP1, J2.MP2, J2.MP3, J2.MP4, J3.1, J4.G1 (GND_1), J4.G2 (GND_2), J4.G3 (GND_3), J4.G4 (GND_4), J4.P6 (VSS), MCP73831.2 (VSS), R1_PWRUSB.1, R2.1, R2-USB.2, R2-USB1.1, R2_BAT.1, R4.1, RESET_BUTTON.1, RESET_BUTTON.2, SENSOR2.1 (GND), SENSOR2.5 (SDO), SENSOR2.7 (GND), SJ1.1, TP4.TP, TP5.TP, U1.4 (GND), U1.9 (EXP), U2.1 (GND), U2.28 (GND), U2.29_1 (GND), U2.29_2 (GND), U2.29_3 (GND), U2.29_4 (GND), U2.29_5 (GND), U2.29_6 (GND), U2.29_7 (GND), U2.29_8 (GND), U2.29_9 (GND), U3.13 (GND), U4.1 (CTG), U4.4 (GND), U4.6 (QSTRT), U4.9 (EP)
GPIO8: R1.1, U2.10 (IO8)
I2C_PW: C1.1, C2.1, R1_PINH.2, R2_PINH.2, SENSOR2.2 (CSB), SENSOR2.6 (VDDIO), SENSOR2.8 (VDD), U2.17 (IO19)
INT_RTC: R1_PINH1.2, TP15.TP, U2.8 (IO0), U3.3 (SQW/!INT)
IO/BOOT: BOOT_BUTTON.3, BOOT_BUTTON.4, C6.1, R_BOOT.1, U2.15 (IO9)
IO/CHANGE: C10.1, CHANGE_BUTTON.3, CHANGE_BUTTON.4, R_CHANGE.1, U2.23 (IO15)
MISO: D12.2, J4.P7 (DAT0), R8.1, TP6.TP, U1.2 (DO(IO1)), U2.27 (IO2)
MOSI: D11.2, J1.14, J4.P3 (CMD), R7.1, TP7.TP, U1.5 (DI(IO0)), U2.7 (IO7)
unnamed: C4.1, D3.2 (A), D4.1 (K)
unnamed: J2.A5, R2-USB1.2
unnamed: MCP73831.1 (STAT), R1_BAT.2
unnamed: C1_BAT1.1, D2.1 (CATHODE), IC4.1 (VIN), IC4.3 (CE), Q1.2 (S)
unnamed: CHG_LED.C, R1_BAT.1
unnamed: MCP73831.5 (PROG), R2_BAT.2
unnamed: EPD_C12.2, J1.24
unnamed: EPD_C8.2, J1.20
unnamed: EPD_C10.2, J1.22
unnamed: EPD_C7.2, J1.19
unnamed: EPD_C6.2, J1.18
unnamed: J2.B5, R2-USB.1
unnamed: EPD_C2.2, J1.5
unnamed: EPD_C1.2, J1.4
unnamed: C_DELAY.1, IC1.5 (CT)
unnamed: D7.1 (CATHODE), R_CAPACITOR.2
PREVGH: D5.1 (K), EPD_C9.2, J1.21
PREVGL: D4.2 (A), EPD_C11.2, J1.23
RESE: J1.3, Q3.2 (S), R3.2
RESE': R2.2, R3.1, SJ1.2
RESET: C5.1, IC1.1 (VOUT), RESET_BUTTON.3, RESET_BUTTON.4, R_RESET.1, U2.3 (EN)
RTC_RST: U2.16 (IO18), U3.4 (!RST)
RX: TP2.TP, U2.24 (RXD0/GPIO17)
SCK: D10.2, J1.13, J4.P5 (CLK), R6.1, TP8.TP, U1.6 (CLK), U2.6 (IO6)
SCL: J3.4, R2_PINH.1, SENSOR2.4 (SCK), U2.20 (IO22), U3.16 (SCL), U4.7 (SCL)
SDA: J3.3, R1_PINH.1, SENSOR2.3 (SDI), U2.19 (IO21), U3.15 (SDA), U4.8 (SDA)
SRC: C4.2, D5.2 (A), L1.1, Q3.3 (D)
SS_SD: D8.2, J4.P2 (CD/DAT3), R10.1, U2.4 (IO4)
TX: TP1.TP, U2.25 (TXD0/GPIO16)
USB_D+: D1.1 (I/O1_1), U2.14 (IO13)
USB_D-: D1.3 (I/O2_1), U2.13 (IO12)
VBAT: C2_BAT.1, MCP73831.3 (VBAT), Q1.3 (D), TP3.TP, U4.2 (CELL), U4.3 (VDD)
VBUS: C1_BAT.1, C4_USB.1, C5_USB.1, CHG_LED.A, D1.5 (VBUS), D2.2 (ANODE), MCP73831.4 (VIN), PFMF.050.1.2, Q1.1 (G), R1_PWRUSB.2, TP14.TP
VRTC: C8.2, C10_SUPERCAP.1, R_CAPACITOR.1, U3.14 (VBAT)
VUSB: J2.A4, J2.A9, J2.B4, J2.B9, PFMF.050.1.1

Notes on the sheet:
USB C connector & ESD protection
LDO Voltage Regulator
SD Card
ESP32 C6
Display Type Selector
E-Paper Drive Circuit
Li-Po Battery Chargind Controller
E-Paper Display Header
EPD Power
Environmental Sensor BME688
Voltage Supervisor + Reset &
Boot / IO Button
Battery Charge Level
External NOR Flash 64MB
SPI ESD Protection Lines
Qwiic /
Stemma QT
Test Pads
RTC Module DS3231SN

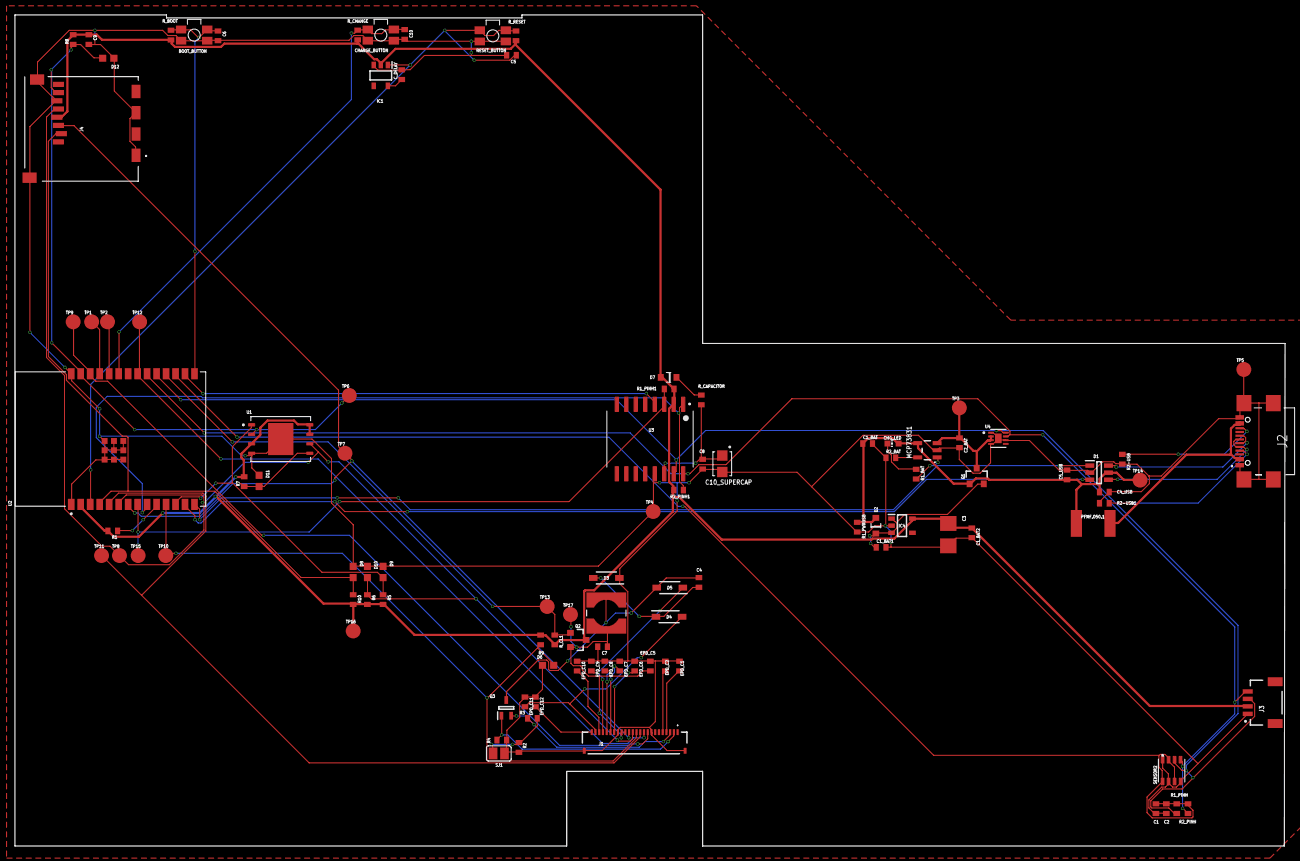
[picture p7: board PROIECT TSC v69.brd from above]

Board: 2 copper layers, 170.1 x 111.3 mm, 103 parts (0 on the bottom side), 55 nets.

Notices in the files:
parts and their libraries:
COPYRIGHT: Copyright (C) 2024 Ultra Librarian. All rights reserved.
